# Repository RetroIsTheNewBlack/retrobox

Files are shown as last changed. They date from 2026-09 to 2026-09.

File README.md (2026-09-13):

# retrobox
A Steam Machine style case for your PC / Raspberry Pi 4/5 or MiSTer.

You can 3D print this at home on a standard 200mmx200mmm printbed. Check out the bom.xlsx for details on the parts needed if you want to put a PI or a MiSTer into the case. 

There are build videos available:

Part 1 (General infos): https://youtu.be/ww5rdT14suU

Part 2 (Raspberry PI):

Part 3 (MiSTer): 

How to build:
Step 0: Order all needed parts from the bom.xlsx

Step 1: Print all the parts needed for your project
Print at least MM_Main_CubeCase, MM_Button, one of the xxx_Tray files and one of the xx_Buttoncover files. If you use the xx_Buttoncover_only variant, also print MM_LightstripCover_only. 

MM_Empty_Tray has no cutouts. It's a blank tray to create your own.

Step 2: Put two threaded inserts into the MM_Main_CubeCase and four threaded inserts into the xxx_Tray. Use the outmost four holes on the tray. 

Check the videos for full build guides ...

Cyberpunk Edition
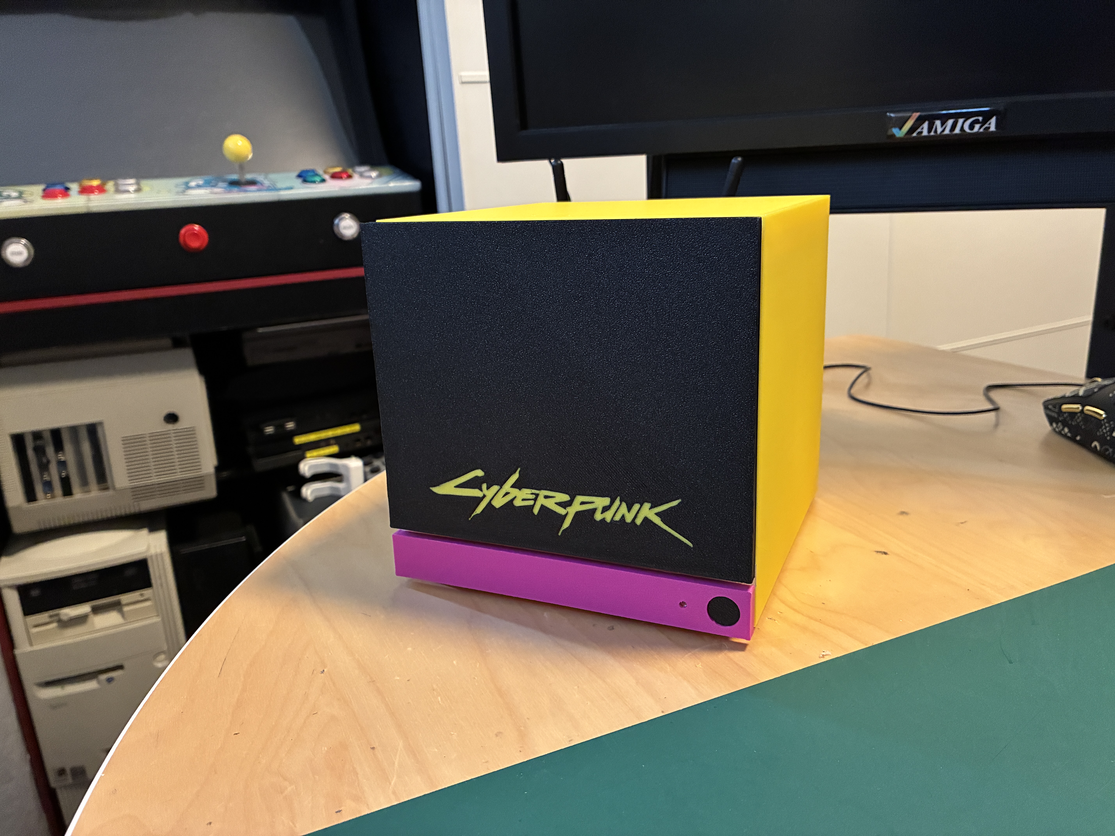
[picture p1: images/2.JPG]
Cyberpunk Edition


PI Edition
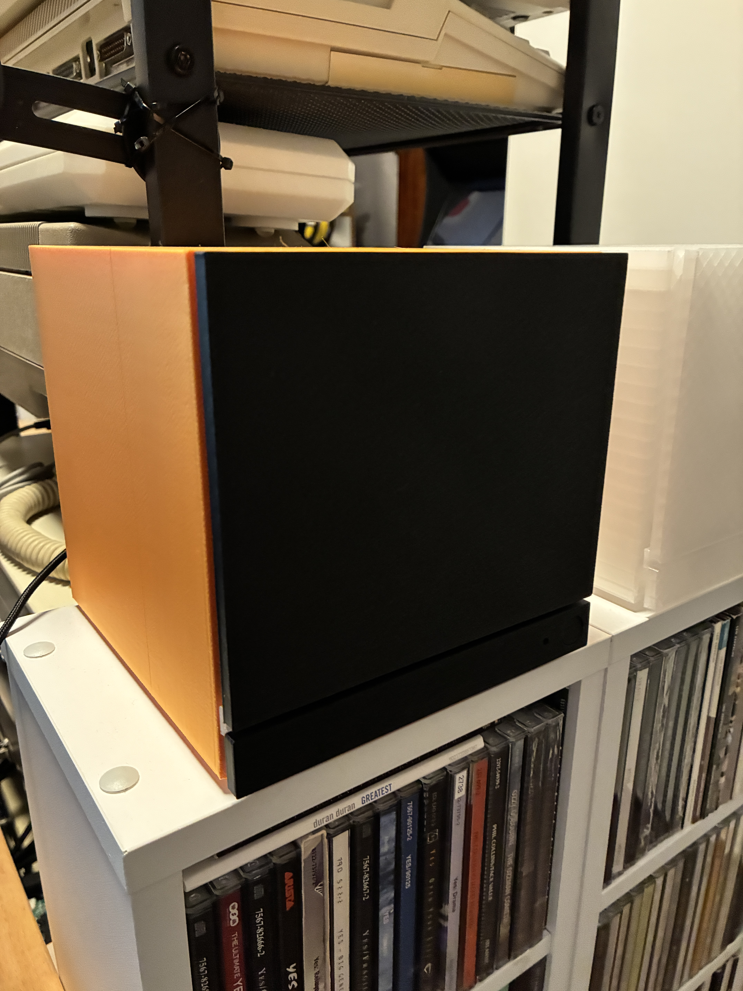
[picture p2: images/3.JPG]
PI Edition


Clear Edition
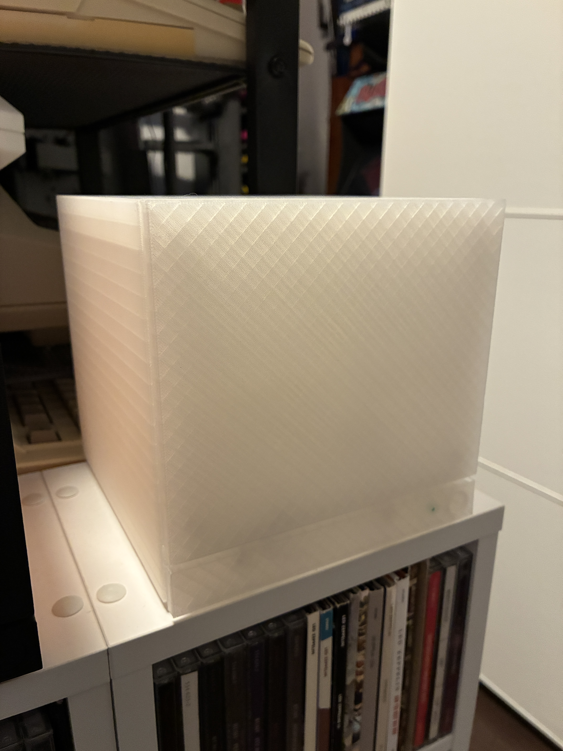
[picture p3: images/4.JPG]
Clear Edition


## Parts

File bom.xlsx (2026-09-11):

BOM for the MiSTer Machine |  | Links are just for reference
3D Printed Parts:
Amount | Part | Link | Comment
1 | Cube Case
1 | Cube Tray (Raspi or MiSTer) |  | Select either Raspi or MiSTer version
1 | Power Button
1 | Button Frontpanel |  | Select one
1 | Main Frontpanel |  | Select one
Optional | Blinds for unused cutouts in the tray
Material:
Amount | Part | Link | Comment
1 | LED 3mm (Green, Yellow or Red) - Small | https://www.amazon.de/blinkende-LED-Dioden-Gl%C3%BChbirne-Elektronikkomponenten-Anzeigeleuchtdioden/dp/B0895MYM4F
1 | LED Bar 12V | https://www.amazon.de/dp/B0CKBSH88W
1 | Step-Up Converter 5V => 9V | https://www.amazon.de/GTIWUNG-Step-up-Converter-Spannungsregler-Netzteilmodul/dp/B0D2CSHWC4
12 | Magnet 5mmx3mm | https://www.amazon.de/dp/B097MJLY51
1 | Push Button 9.5mm | https://www.amazon.de/Taktilen-Druckschalter-Taktiler-Drucktastenschalter-Tactile/dp/B082ZL867J
14 | Threaded Inserts 3mm inside (5mm outside) | https://www.amazon.de/Gewindeeinsatz-Einschmelzgewinde-Einpressmuttern-Gewindebuchse-Kunststoffschale/dp/B0D17FGQWW
13 | Screws 3mm x 10mm | https://www.amazon.de/sourcing-Metrisch-Innensechskant-Flachkopf-Schrauben/dp/B072JP1HN8
4 | Rubber Feet (10mm) | https://www.amazon.de/St%C3%BCck-Transparente-Gummipuffer-Selbstklebend-ger%C3%A4uschd%C3%A4mpfend/dp/B0G7X3FK83
1 | Resistor 220 to 300 Ohms
 | Some wire
 | Hot glue
Optional material for RaspPi:
Amount | Part | Link | Comment
1 | Latching Button 12mm | https://www.amazon.de/Gebildet-Vorverkabelt-Druckknopfschalter-Tischlampe-Haushaltsger%C3%A4te/dp/B083K24XF6
1 | 3mm Audio Jack | https://www.amazon.de/Newyuan-Klinkenbuchse-Panelmontage-Gewinde-L%C3%B6tanschluss-Schwarz/dp/B0GTQ54914
1 | USB-C Power Port | https://www.amazon.de/Mumjooyi-USB-Buchse-Schnelllade-Typ-C-Buchse-Schnappnut-Panelmontage/dp/B0CZLD8NKS
1 | SD Card extender | https://www.amazon.de/dp/B0GQDNCKK7
Optional material for MiSTer:
Amount | Part | Link | Comment
1 | Latching Button 12mm | https://www.amazon.de/Gebildet-Vorverkabelt-Druckknopfschalter-Tischlampe-Haushaltsger%C3%A4te/dp/B083K24XF6
1 | USB-C Power Port | https://www.amazon.de/Mumjooyi-USB-Buchse-Schnelllade-Typ-C-Buchse-Schnappnut-Panelmontage/dp/B0CZLD8NKS
1 | SD Card extender | https://www.amazon.de/dp/B0GQDNCKK7
5 | USB type A ports | https://www.amazon.de/dp/B0DZCMM5Q1
3 | Drucktaster (Reset, User, OSD) | https://www.amazon.de/GTIWUNG-Momentanen-DruckTaster-Wasserdicht-Druckknopf/dp/B08JCNHF1H

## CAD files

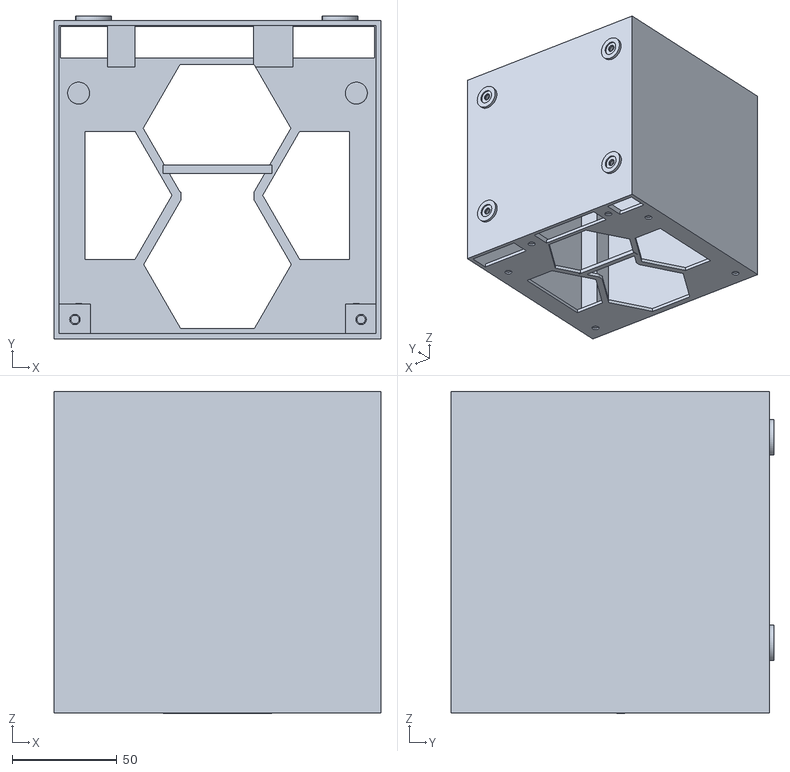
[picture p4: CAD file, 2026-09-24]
MM_Main_CubeCase.stl
156.0 x 154.0 x 153.7

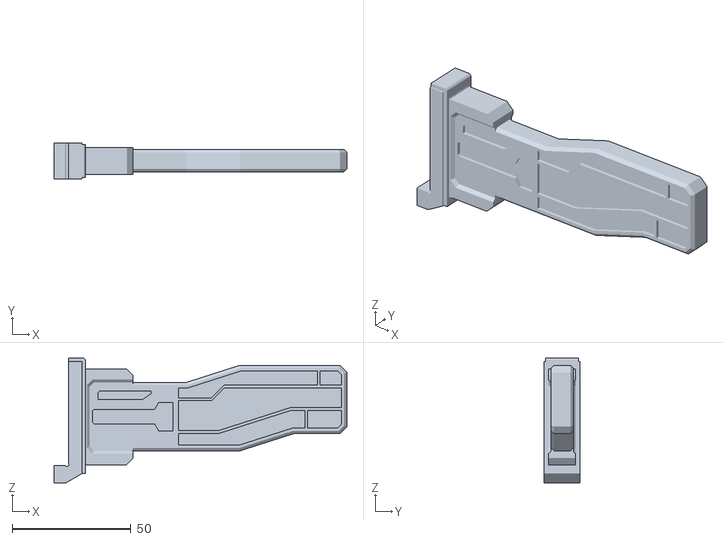
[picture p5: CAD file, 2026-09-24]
MM_Shard_SwitchOnly.stl
123.5 x 15.2 x 52.6

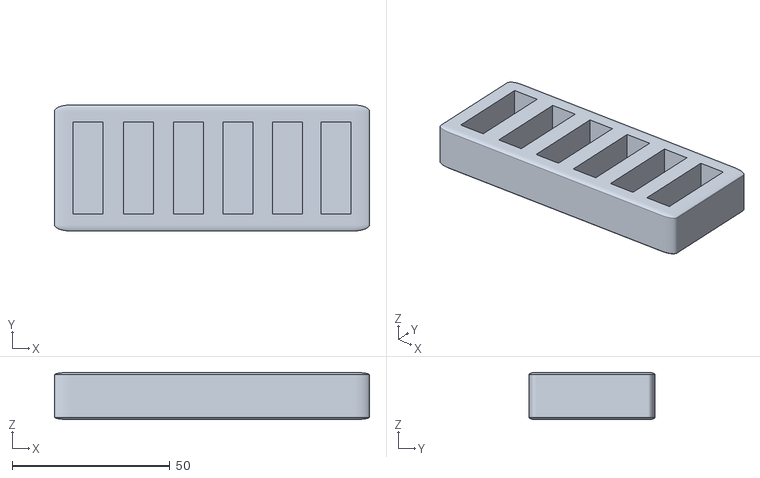
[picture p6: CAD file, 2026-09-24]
MM_Shardstand.stl
100.0 x 40.0 x 15.0

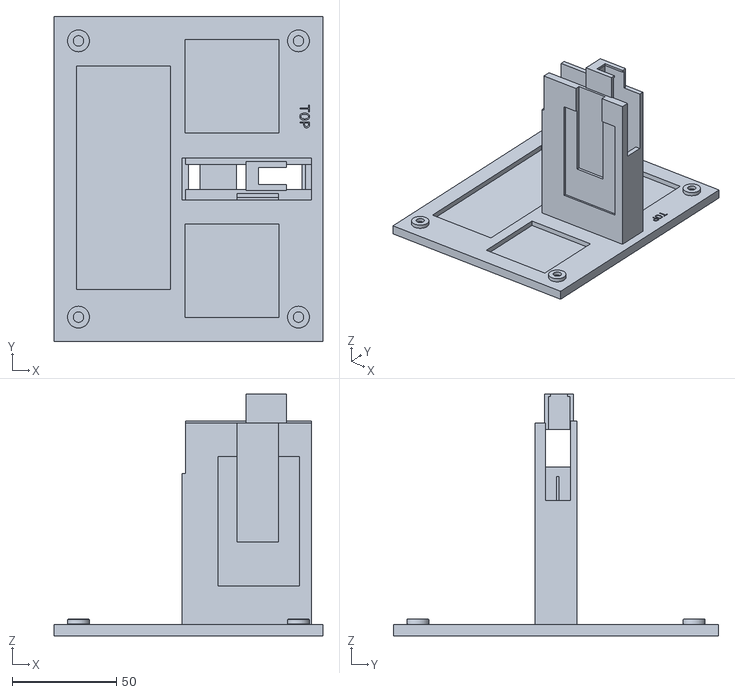
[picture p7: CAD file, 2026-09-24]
MM_Frontplate_Shardslot.stl
129.0 x 156.0 x 116.0

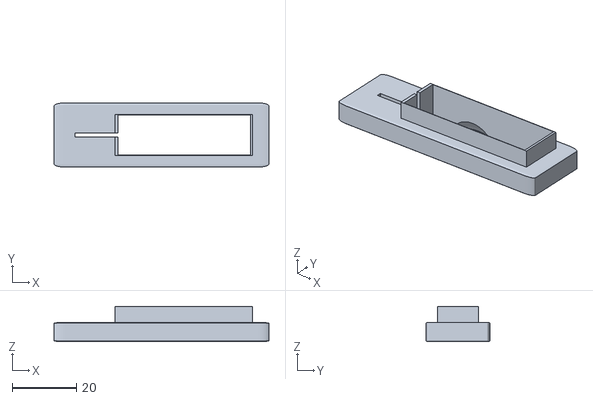
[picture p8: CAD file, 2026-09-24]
MM_Shardslot_cover.stl
67.0 x 20.0 x 11.0

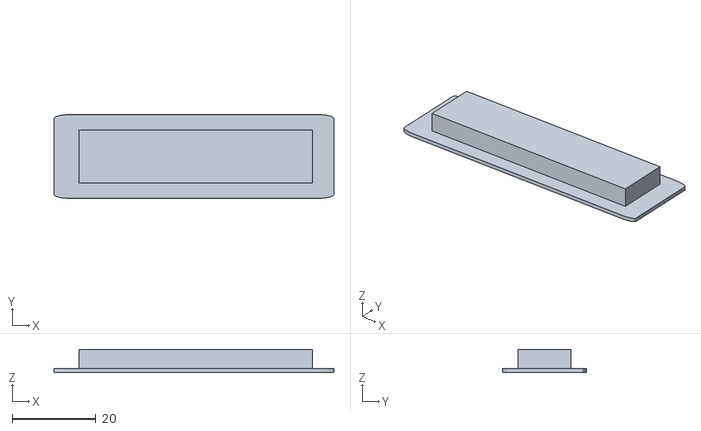
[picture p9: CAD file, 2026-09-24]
MM_Shardslot_blank.stl
67.0 x 20.0 x 5.60

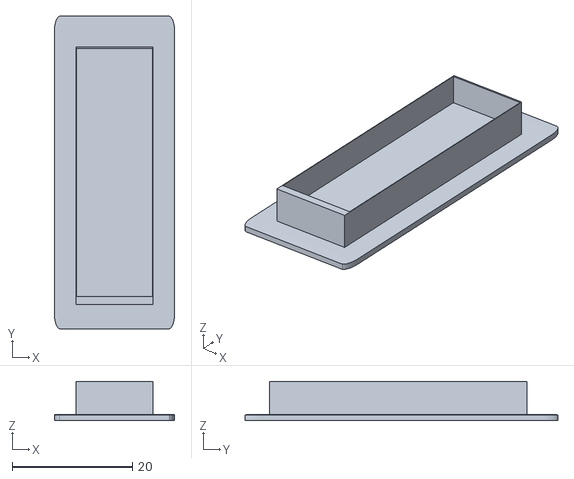
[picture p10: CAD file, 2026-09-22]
MM_Shard_Slot_Blind.stl
20.0 x 52.0 x 6.50

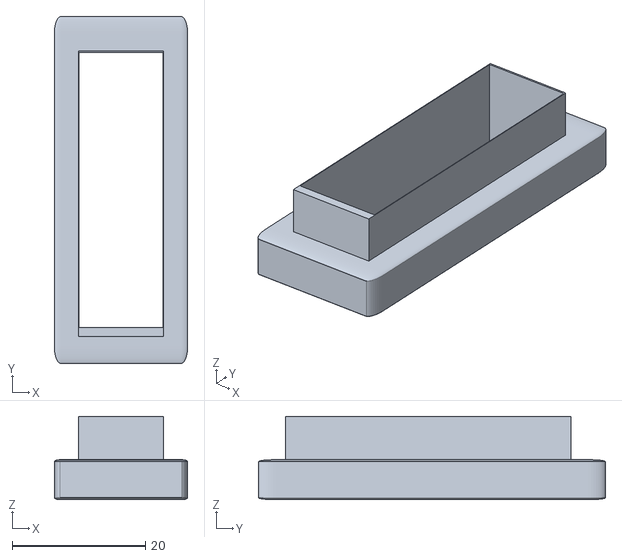
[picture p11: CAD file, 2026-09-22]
MM_Shard_Slot.stl
20.0 x 52.0 x 12.5

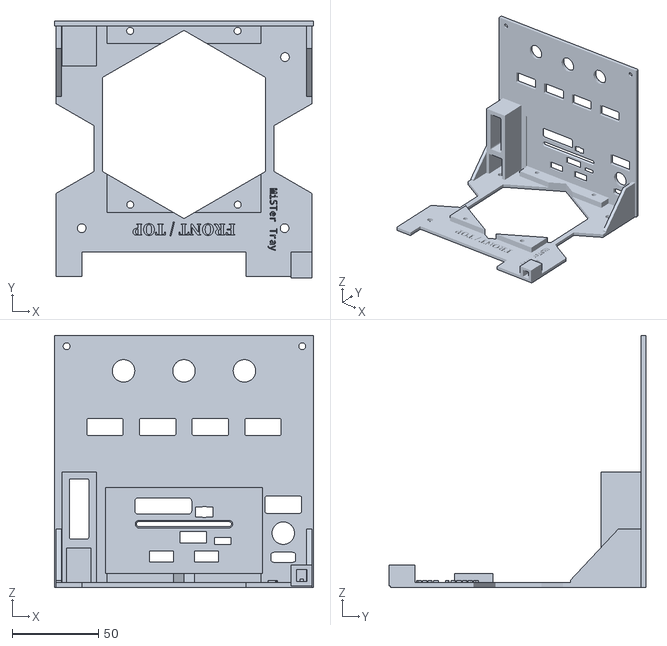
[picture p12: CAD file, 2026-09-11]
MM_MiSTer_Tray.stl
150.0 x 149.0 x 146.0

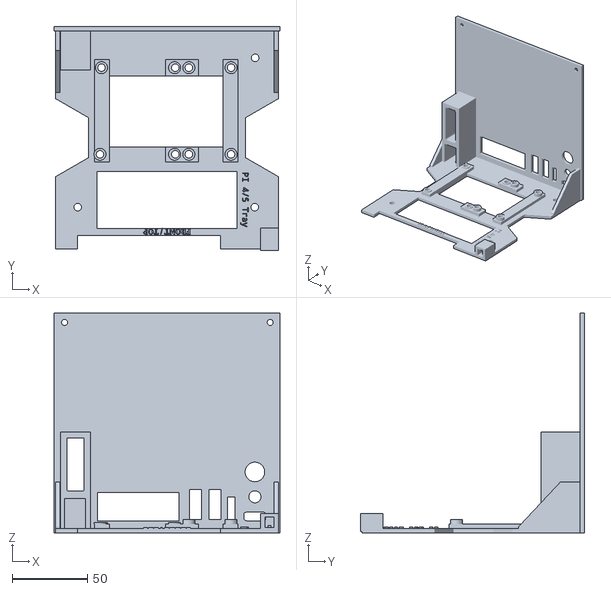
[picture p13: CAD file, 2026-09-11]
MM_Raspi_Tray.stl
150.0 x 149.0 x 146.0

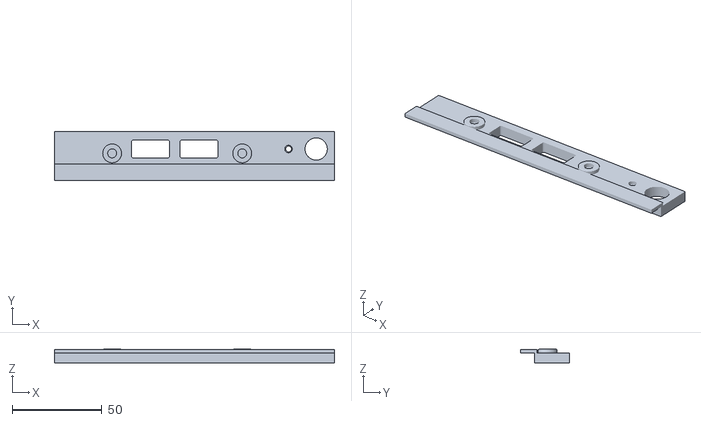
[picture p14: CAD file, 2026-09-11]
MM_Buttoncover_with_LightstripCover_and_USB.stl
156.0 x 27.3 x 7.60

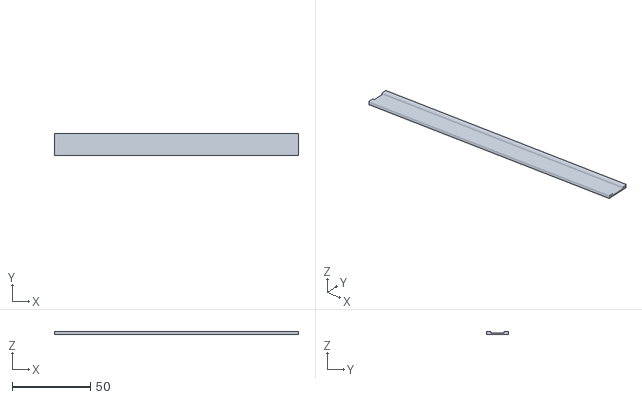
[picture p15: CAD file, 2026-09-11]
MM_LightstripCover_only.stl
156.0 x 14.0 x 2.00

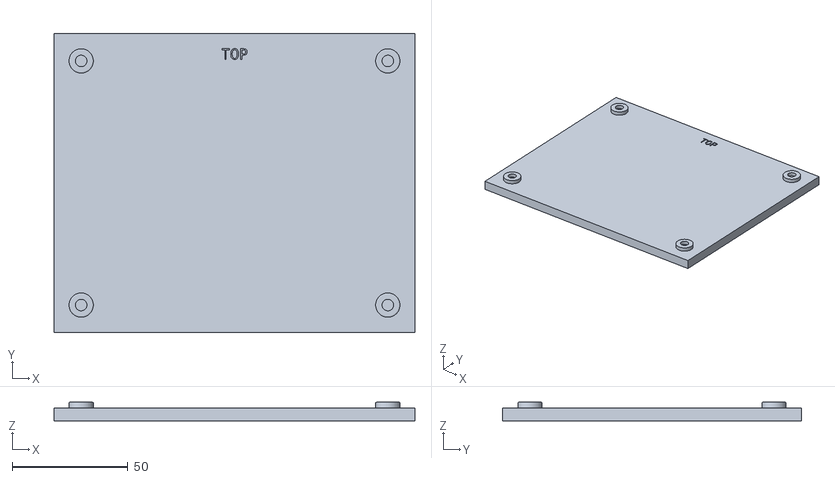
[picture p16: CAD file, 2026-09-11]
MM_Frontcover_Blank.stl
156.0 x 129.0 x 8.10

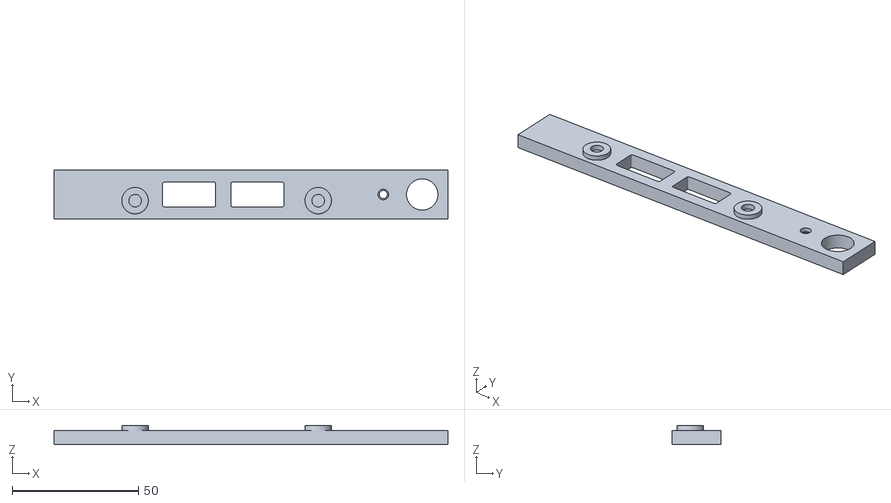
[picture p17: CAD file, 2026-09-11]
MM_Buttoncover_only_with_USB.stl
156.0 x 19.5 x 7.60

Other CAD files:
MM_Shard_RFID.stl
MM_Frontplate_Shardslot_Cyberpunk.stl
MM_Empty_Tray.stl
MM_Buttoncover_only_no_USB.stl
MM_Blind_Round.stl
MM_Blind_Square.stl
MM_Button.stl
MM_Button_Adapter_12mmTo6mm.stl
MM_Buttoncover_with_LightstripCover_no_USB.stl
MM_Frontcover_Cyberpunk.stl

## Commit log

2026-09-11 Version 1.0 - Sept. 2026
    [MM_Blind_Round.stl, MM_Blind_Square.stl, MM_Button.stl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]
2026-09-11 Update README with printing instructions and video links
    Added additional details about 3D printing and build videos.
2026-09-13 Add build instructions to README
    Added a 'How to build' section with detailed steps for assembling the project, including part ordering and printing instructions.
2026-09-22 Add files via upload
    Reduced print time by 2 hours. News design to accomodate for card-reader.
    [MM_Main_CubeCase.stl]
2026-09-22 New Shard Slots (and blind) for the card reader tray.
    [MM_Shard_Slot.stl, MM_Shard_Slot_Blind.stl]
2026-09-24 Front Cardslot for RFID reader and shards added
    [MM_Frontplate_Shardslot.stl, MM_Frontplate_Shardslot_Cyberpunk.stl, MM_Shard_RFID.stl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]
2026-09-24 Label for Shards and Updated the Cube case
    [MM_Main_CubeCase.stl, MM_Shard_RFID.stl, MM_Shard_SwitchOnly.stl]
